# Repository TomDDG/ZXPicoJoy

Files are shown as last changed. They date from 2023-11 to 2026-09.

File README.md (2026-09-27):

# ZXPicoJoy
Programmable Joystick Interface for the ZX Spectrum using a Raspberry Pico.

Supports:
- Kempston
- Sinclair 1 & 2
- Cursor
- Any key combination

Uses an OLED and buttons to program and does not interfere with the Spectrum unless it is supposed to.

## The PCB
PCB designed to have all the components on the side away from the Spectrum to give more room. The edge connector then sits on the back side as well as the OLED so this is visible to the user. This is also why the buttons are reversed. 
### PCB v1.6c Front
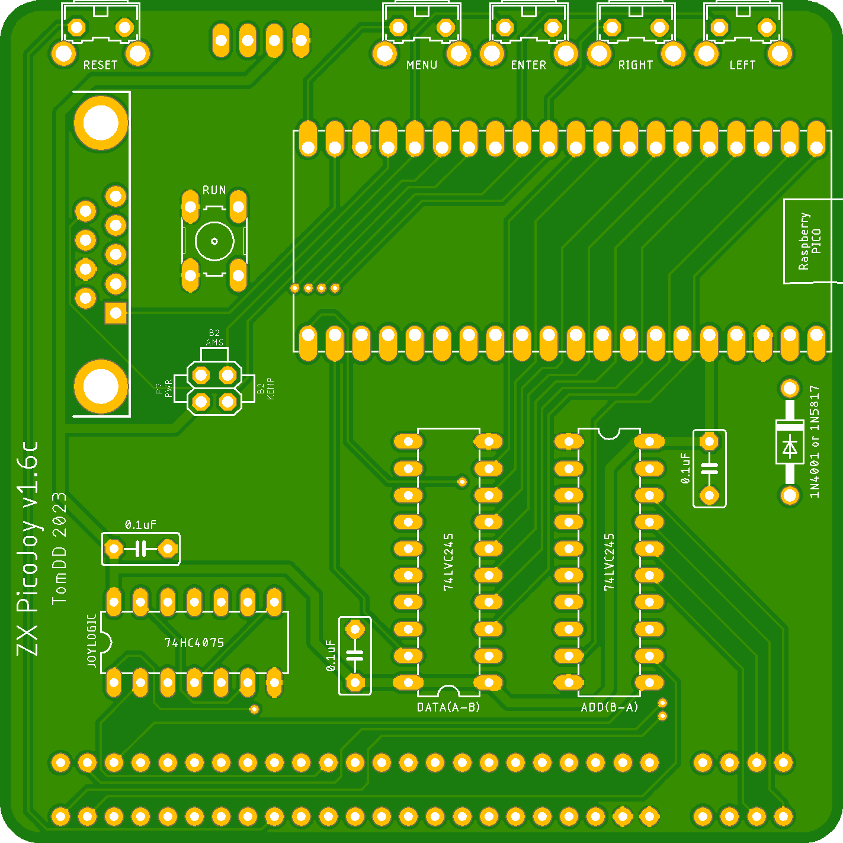
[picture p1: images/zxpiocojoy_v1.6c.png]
PCB Front

### PCB v1.6c Back
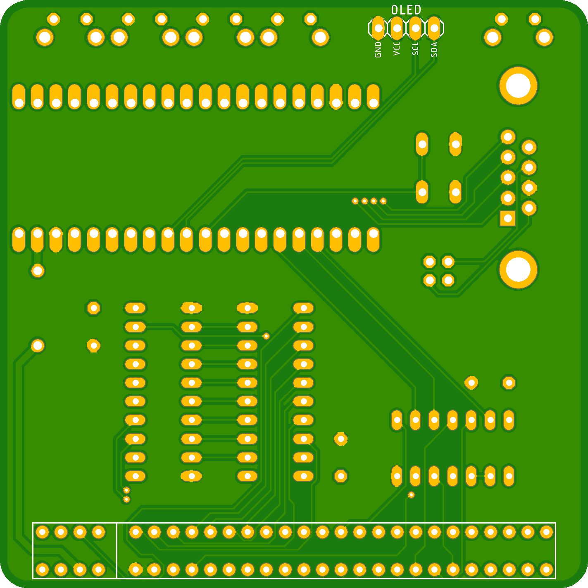
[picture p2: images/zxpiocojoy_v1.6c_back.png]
PCB Back


### Joystick Pin-Out

The joystick is wired for 3 button Kempston (Amiga) with the option to flip button 2 to pin 7 enabling the use of 2 button Amstrad joysticks. There is also an option to supply power to pin 7 for autofire circuits. It is wired to 3V3 instead of 5V so may not work on all joysticks, however, all the ones I have tried work fine as they are simple transistor circuits.

- Pin 1: Up
- Pin 2: Down
- Pin 3: Left
- Pin 4: Right
- Pin 5: Button 3
- Pin 6: Button 1
- Pin 7: Button 2 for Amstrad compatibility, not connected or 3V3
- Pin 8: GND
- Pin 9: Button 2 or not connected

### Bill of Materials (BoM)
- 1x [Raspberry Pico](https://shop.pimoroni.com/products/raspberry-pi-pico?variant=40059364311123). Recommend H variant as header pre-soldered.
- 2x [SN74LVC245AN Octal Bus Transceiver With 3-State Outputs](https://www.mouser.co.uk/ProductDetail/595-SN74LVC245AN). Note these need to be the LVC variant to work with the 3v3 of the Pico.
  - Optional 2x10pin sockets
- 1x [CDx4HC4075 Triple 3-Input OR Gates](https://www.mouser.co.uk/ProductDetail/595-CD74HC4075EE4). Note these need to be the HC variant in order to work with 3V3 supply voltage.
  - Optional 2x7pin socket
- 3x [100nF/0.1uF Capacitor](https://www.mouser.co.uk/ProductDetail/Vishay-BC-Components/K104K15X7RF5TH5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) 
- 1x [1N4001 Diode](https://www.mouser.co.uk/ProductDetail/Rectron/1N4001-B?qs=%252BtLcN0raKGUACwkD5chVvg%3D%3D) or [1N5158 Diode](https://www.mouser.co.uk/ProductDetail/STMicroelectronics/1N5817?qs=JV7lzlMm3yKNnxZdh%252BSMnw%3D%3D)
- 1x [56pin PCB Edge Connector](https://www.ebay.co.uk/sch/i.html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). Needs both ends cutting off, the pins removing top & bottom at position 5 and a piece of plastic or metal inserting for the slot (see [ZX Spectrum Edge Connector](https://i0.wp.com/projectspeccy.com/documents/ZXSpectrum_Edge_Connector_Diagram_48K.jpg)). This ensures everything aligns when connecting.
- 2x [20pin female header sockets](https://www.ebay.co.uk/sch/i.html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)
- 5x [6x6x9mm Right Angled PCB Momentary Push Button](https://www.ebay.co.uk/sch/i.html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)
- 1x [6x6x9mm PCB Momentary Push Button](https://www.ebay.co.uk/sch/i.html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)
- 1x [DE9 9pin Male PCB Connector](https://www.ebay.co.uk/sch/i.html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)
- 1x 4pin PCB header socket 2.54mm Pitch
- 1x SSD1306 OLED 0.96" (you can get larger ones just make sure they are SSD1306). Be very careful of the GND & VCC placement as they are sometimes reversed.
- 1x 2x2pin PCB pin header + jumpers

### Photos
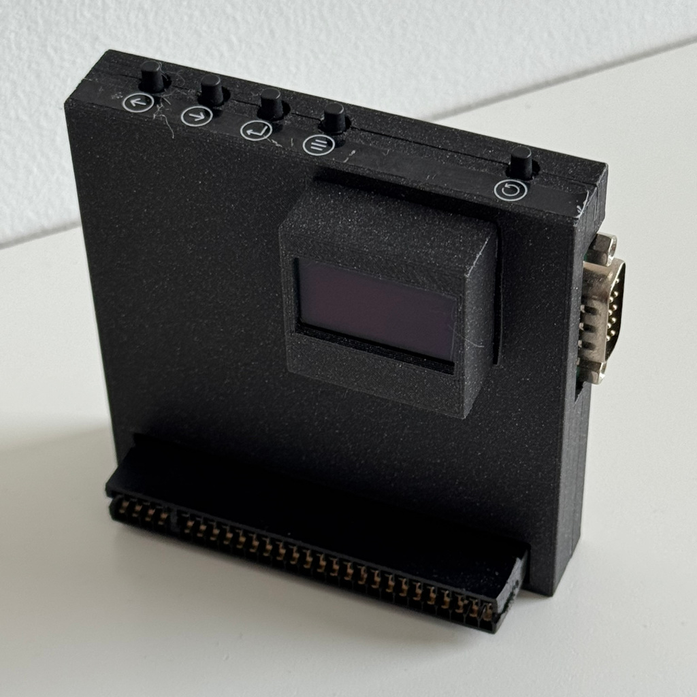
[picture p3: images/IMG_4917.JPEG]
Unit Front

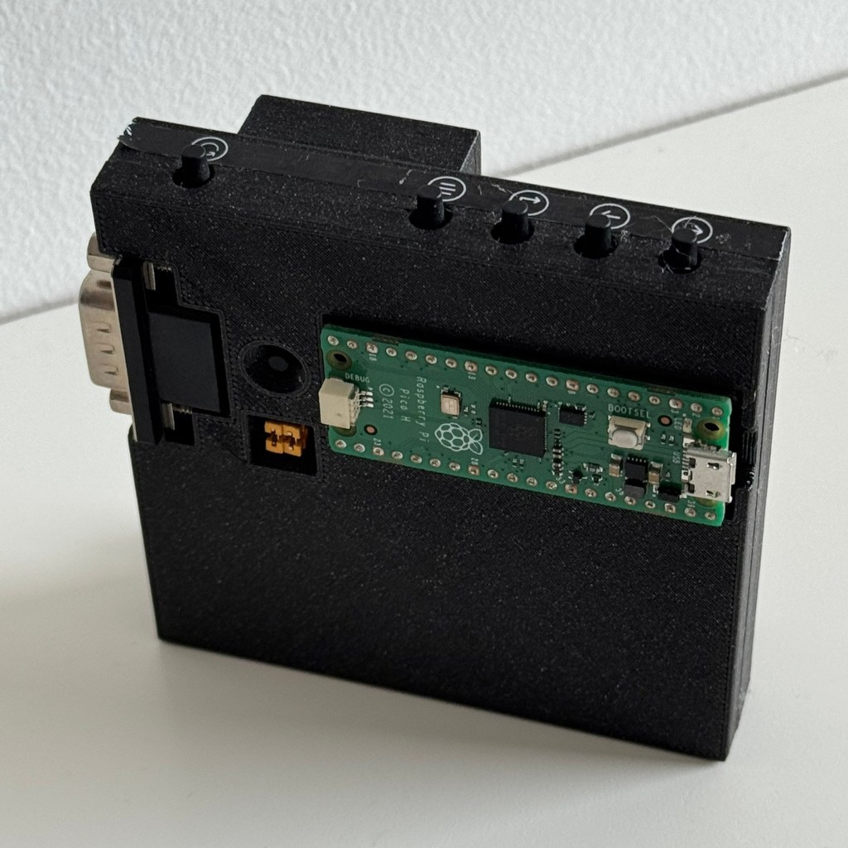
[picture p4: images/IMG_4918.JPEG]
Unit Back

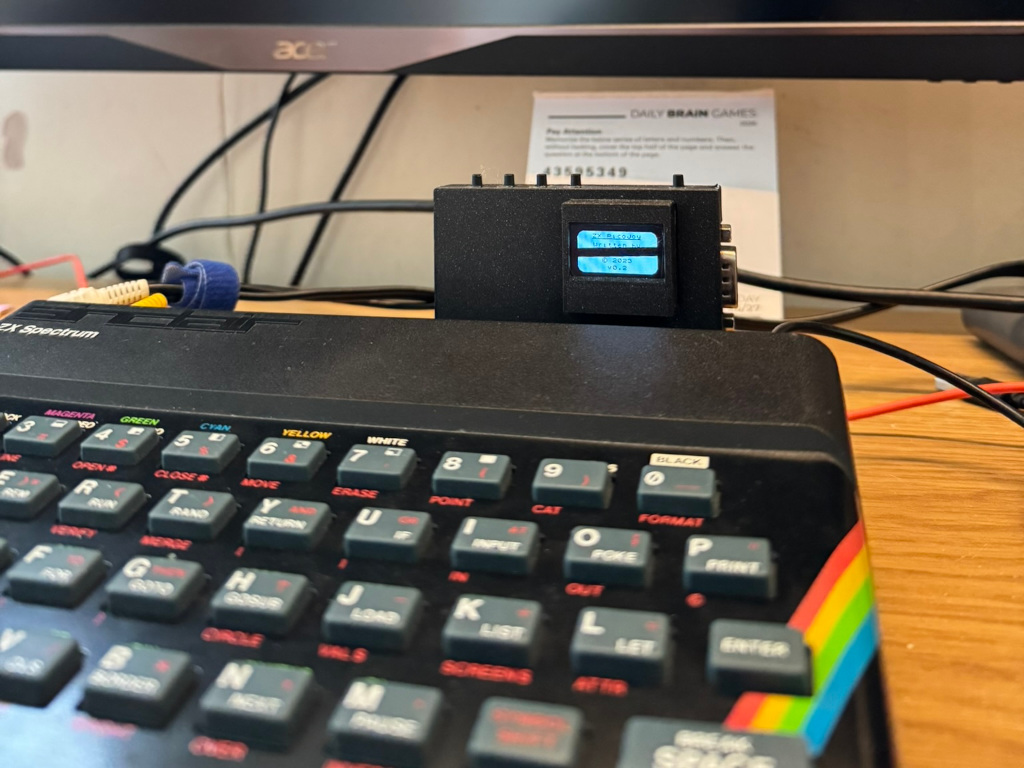
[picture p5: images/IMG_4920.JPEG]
Plugged In

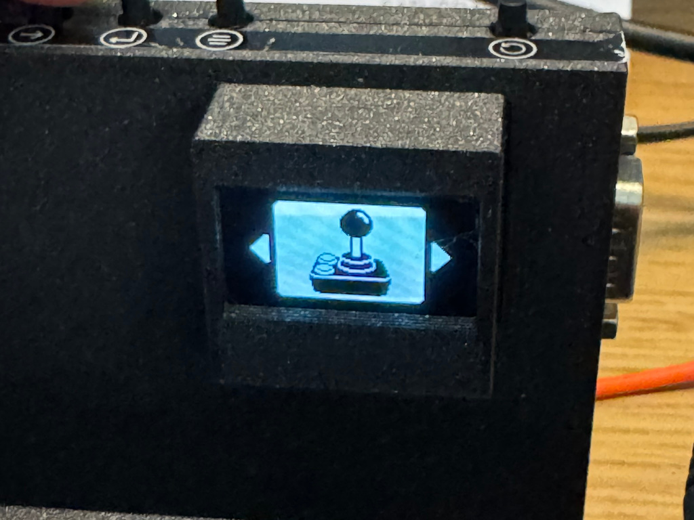
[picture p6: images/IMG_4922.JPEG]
Option 1

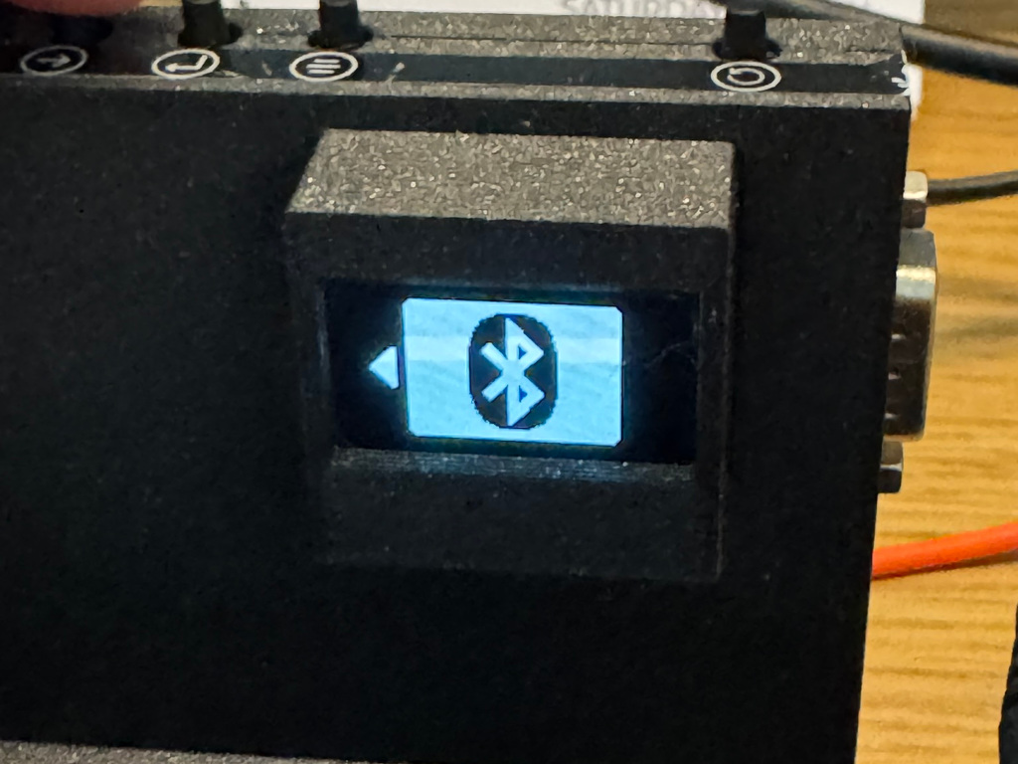
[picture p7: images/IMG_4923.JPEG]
Option 3

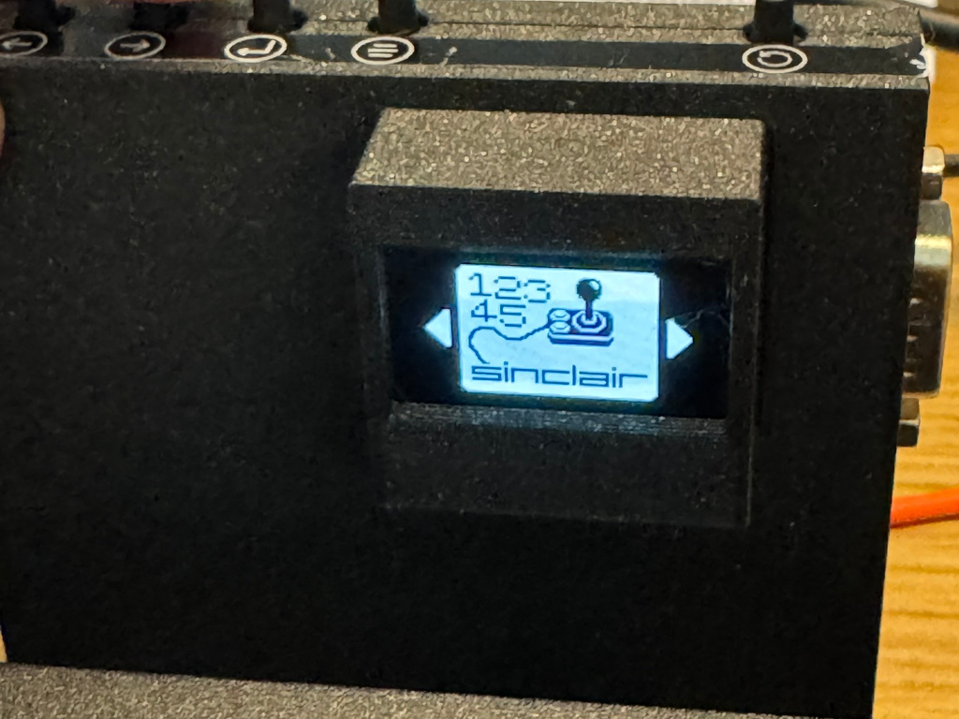
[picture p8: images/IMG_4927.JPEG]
Option 4

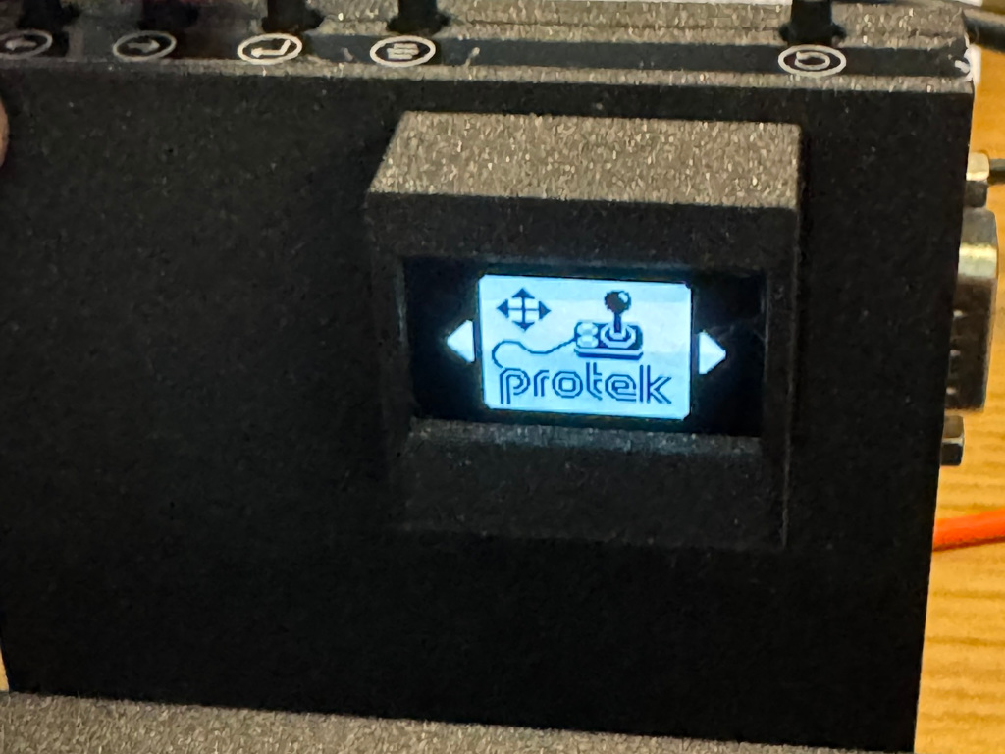
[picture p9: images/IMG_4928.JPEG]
Option 5

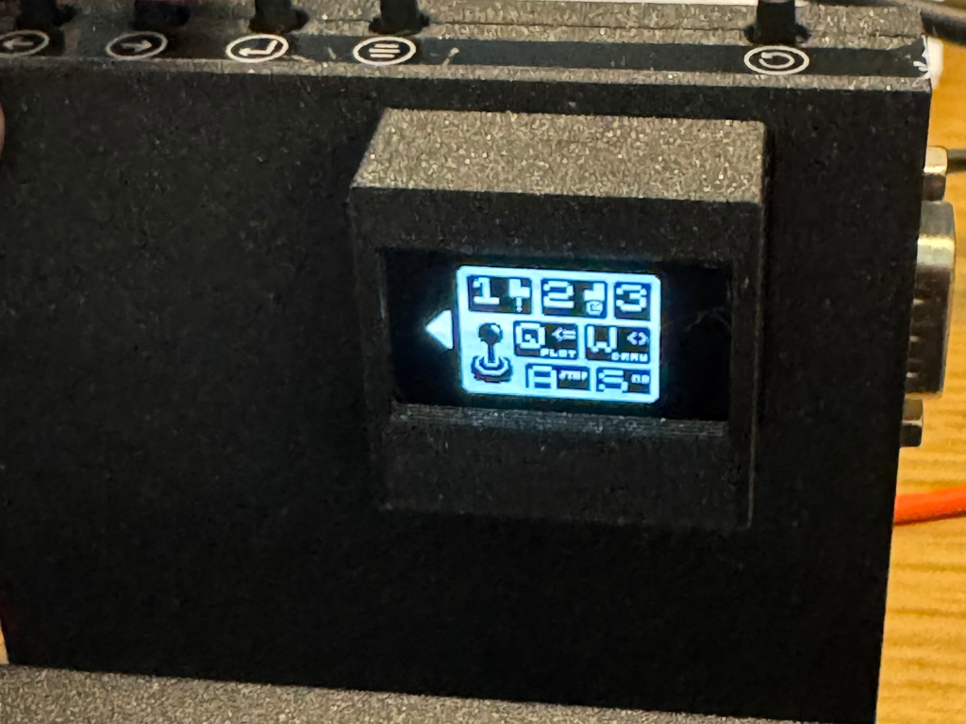
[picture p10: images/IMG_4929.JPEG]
Option 7


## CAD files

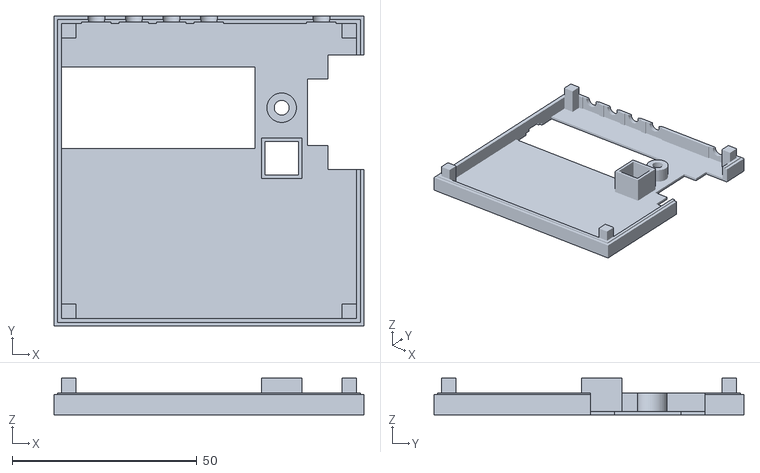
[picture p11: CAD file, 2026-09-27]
stl/zxpicojoy_top_v1.6bPCB_v0.1.stl
84.0 x 84.0 x 10.0

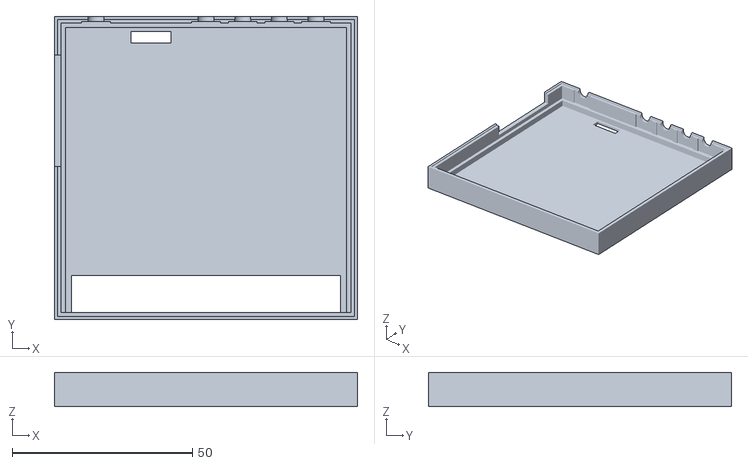
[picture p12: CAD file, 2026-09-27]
stl/zxpicojoy_bottom_v0.1.stl
84.0 x 84.0 x 9.50

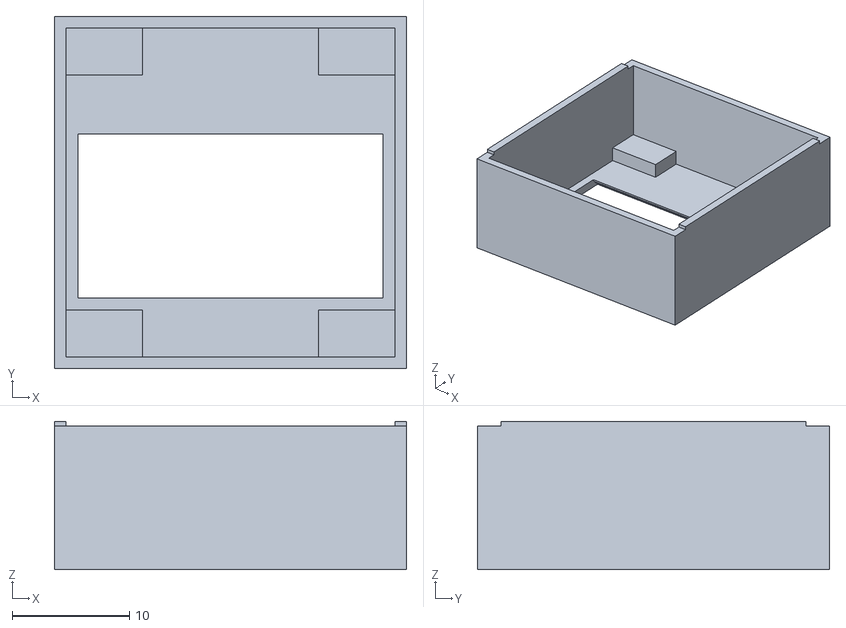
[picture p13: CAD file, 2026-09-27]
stl/zxpicojoy_oled_v0.2.stl
30.0 x 30.0 x 12.6

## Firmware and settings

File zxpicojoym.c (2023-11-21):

// Versions
// v0.1 initial release copied from v0.2 of ZX PicoJoy
// v0.2 added button 3 mapping
//
#define PROG_NAME   "ZX PicoJoyM"
#define VERSION_NUM "v0.2"
//
// ---------------------------------------------------------------------------
// includes
// ---------------------------------------------------------------------------
#include <stdio.h>
#include <string.h>
#include <stdlib.h>
#include "pico/stdlib.h"
//
#include "zxpicojoym.pio.h"
#include "zxpicojoym_k.pio.h"
#include "zxpicojoypress.pio.h"
//
#include "hardware/pio.h"
#include "hardware/dma.h"
#include "hardware/flash.h"
#include "hardware/i2c.h" // for OLED
//
#define SET_SPLASH 2000
#define KEY_REPEAT_LONG 500000
#define KEY_REPEAT_SHORT 200000
//
// ---------------------------------------------------------------------------
// GPIO Assignments
// ---------------------------------------------------------------------------
// 0 A8/D0
#define PIN_A8D0    0
// 1 A9/D1
// 2 A10/D2
// 3 A11/D3
// 4 A12/D4
// 5 A13/D5
// 6 A14/D6
// 7 A15/D7
//
// 8 RIGHT (ph) rldu123m
#define MAP_MBUDLR  0b1001111100000000
#define MAP_MBLR    0b1001001100000000
//
#define PIN_RIGHT   8
#define MAP_RIGHT   0b0000000100000000
// 9 LEFT (ph)
#define PIN_LEFT    9
#define MAP_LEFT    0b0000001000000000
// 10 DOWN (ph)
#define PIN_DOWN    10
#define MAP_DOWN    0b0000010000000000
// 11 UP (ph)
#define PIN_UP      11
#define MAP_UP      0b0000100000000000
// 12 BUTTON 1 (ph) also ENTER in MENU
#define PIN_B1      12
#define MAP_B1      0b0001000000000000
// 13 BUTTON 2 (ph)
#define PIN_B2      13
#define MAP_B2      0b0010000000000000
// 13 BUTTON 3 (ph)
#define PIN_B3      14
#define MAP_B3      0b0100000000000000
// 15 MENU (ph)
#define PIN_MENU    15
#define MAP_MENU    0b1000000000000000
// 16 ADDON
#define PIN_ADDON   16
// 17 DATAON
#define PIN_DATAON  17
// 18 A5RD
#define PIN_A5RD    18
// 19 KEMP
#define PIN_KEMP    19
// 20 KEYRD
#define PIN_KEYRD   20
// 21 NC
// 22 NC
// 23 NC
// 24 NC
// 25 NC
// 26 SDA (OLED)
#define PIN_SDA     26
// 27 SCL (OLED)
#define PIN_SCL     27
// 28 NC
//
// ---------------------------------------------------------------------------
// I/O Chips
// ---------------------------------------------------------------------------
// BUFFER 1 (3V3) DATA(A-B) -> DATON(P) Switches ON(0)/OFF(1)
// D0A8(P)   -> D0(E)
// D1A9(P)   -> D1(E)
// D2A10(P)   -> D2(E)
// D3A11(P)   -> D3(E)
// D4D12(P)   -> D4(E)
// D5A13(P)   -> D5(E)
// D6A14(P)   -> D6(E)
// D7A15(P)   -> D7(E)
// DATAON OE
//
// BUFFER 2 (3V3) ADD(B-A) -> ALWAY ON
// D0A8(P)  <- A8(E)
// D1A9(P)  <- A9(E)
// D2A10(P) <- A10(E)
// D3A11(P) <- A11(E)
// D4A12(P) <- A12(E)
// D5A13(P) <- A13(E)
// D6A14(P) <- A14(E)
// D7A15(P) <- A15(E)
// ADDON OE
//
// LOGIC OR (3V3)
// IORQ(E)+RD(E)+A0(E)   -> KEYRD(P)
// A5(E)+IORQ(E)+RD(E)   -> A5RD(O)
// A6(E)+A7(E)+A5RD(O)   -> KEMP(P)
//
// ---------------------------------------------------------------------------
// keyRow which address to alter
// keyCol which bit to alter
// ---------------------------------------------------------------------------
    const uint8_t keyRow[]= { 3,3,3,3,3, // 1,2,3,4,5
                              4,4,4,4,4, // 6,7,8,9,0
                              2,2,2,2,2, // Q,W,E,R,T
                              5,5,5,5,5, // Y,U,I,O,P
                              1,1,1,1,1, // A,S,D,F,G
                              6,6,6,6,6, // H,J,K,L,ENTER
                              0,0,0,0,0, // SHIFT,Z,X,C,V
                              7,7,7,7,7, // B,N,M,SS,SPACE
                              0 }; // kempston
    //  
    const uint8_t keyCol[]= {   0b10111110, // 1
                                0b10111101, // 2
                                0b10111011, // 3 
                                0b10110111, // 4
                                0b10101111, // 5
                                //
                                0b10101111, // 6
                                0b10110111, // 7
                                0b10111011, // 8
                                0b10111101, // 9
                                0b10111110, // 0
                                //
                                0b10111110, // Q
                                0b10111101, // W
                                0b10111011, // E
                                0b10110111, // R
                                0b10101111, // T
                                //
                                0b10101111, // Y
                                0b10110111, // U
                                0b10111011, // I
                                0b10111101, // O
                                0b10111110, // P
                                //
                                0b10111110, // A
                                0b10111101, // S
                                0b10111011, // D
                                0b10110111, // F
                                0b10101111, // G
                                //
                                0b10101111, // H
                                0b10110111, // J
                                0b10111011, // K
                                0b10111101, // L
                                0b10111110, // ENTER
                                //
                                0b10111110, // SHIFT
                                0b10111101, // Z
                                0b10111011, // X
                                0b10110111, // C
                                0b10101111, // V
                                //
                                0b10101111, // B
                                0b10110111, // N
                                0b10111011, // M
                                0b10111101, // SS
                                0b10111110, // SPACE
                                //
                                0b11111111 // kempston
                                };
//
// ---------------------------------------------------------------------------
// OLED structure
// ---------------------------------------------------------------------------
typedef struct {
    uint8_t w;      // width 128
    uint8_t h;      // height 64
    uint8_t p;      // pages 8
    uint8_t a;      // i2c address of display
    i2c_inst_t *i;  // i2c connection instance
    bool e;         // whether display uses external vcc
    uint8_t *c;	    // display buffer with command
    uint8_t *b;	    // display buffer 
    size_t s;		// total display buffer size
} oled_t;
#define MEMSIZE 1025 // 128*64=8192bits -> 1024bytes + 1 byte
#define MEMS_OLED 0 // start of main buffer used for OLED buffer
uint8_t mem_buffer[MEMSIZE];
//
// ---------------------------------------------------------------------------
// OLED command constants
// ---------------------------------------------------------------------------
#define SET_CONTRAST        0x81
#define SET_ENTIRE_ON       0xA4
#define SET_NORM_INV        0xA6
#define SET_DISP            0xAE
#define SET_MEM_ADDR        0x20
#define SET_COL_ADDR        0x21
#define SET_PAGE_ADDR       0x22
#define SET_DISP_START_LINE 0x40
#define SET_SEG_REMAP       0xA0
#define SET_MUX_RATIO       0xA8
#define SET_COM_OUT_DIR     0xC0
#define SET_DISP_OFFSET     0xD3
#define SET_COM_PIN_CFG     0xDA
#define SET_DISP_CLK_DIV    0xD5
#define SET_PRECHARGE       0xD9
#define SET_VCOM_DESEL      0xDB
#define SET_CHARGE_PUMP     0x8D
//
// ---------------------------------------------------------------------------
// functions
// ---------------------------------------------------------------------------
void runOLEDcmd(oled_t *pOLED,uint8_t v);
void dtoBuffer(uint8_t *to,const uint8_t *from);
void showOLED(oled_t *pOLED,uint8_t col,uint8_t page,size_t size);
void oledInit(oled_t *pOLED,uint8_t w,uint8_t h,uint8_t a,i2c_inst_t *i,bool e);
void pltIcons(uint8_t row,uint8_t col,const uint8_t *icon,uint8_t *to,bool invert);
void pltAllIcons(uint8_t *to,uint8_t iconStart,uint8_t iconPos);
void pltIcon(const uint8_t *icon,uint8_t *to);
uint8_t getKey(oled_t *pOLED, uint8_t *to,uint8_t iconShift);
void menu(oled_t *pOLED, uint8_t *to);
void writeConfig();
void clrFlash(oled_t *pOLED, uint8_t *to);
void resetAll();
//
// ---------------------------------------------------------------------------
// menu layout
// ---------------------------------------------------------------------------
#include "scr_img.h"
const uint8_t *scrimg[] = { scr_00, // 0
                            scr_01, // 1
                            scr_0101,scr_010001a,scr_010001b,scr_010002,scr_010003, //  2, 3, 4, 5, 6
                            scr_0102,scr_010001a,scr_010001b,scr_010002,scr_010003, //  7, 8, 9,10,11
                            scr_0103,scr_010001a,scr_010001b,scr_010002,scr_010003, // 12,13,14,15,16
                            scr_0104,scr_010001a,scr_010001b,scr_010002,scr_010003, // 17,18,19,20,21
                            scr_0105,scr_010001a,scr_010001b,scr_010501,scr_010502,scr_010503,scr_010504,scr_010505,scr_010002,scr_010003, // 22,23,24,25,26,27,28,29,30,31
                            scr_02, // 32
                            scr_0201,scr_0202, // 33,34
                            scr_010001c, // 35
                            scr_reset // 36
                             }; 
//
// ---------------------------------------------------------------------------
// action on enter press
// ---------------------------------------------------------------------------
// =0 do nothing
// <128 move to screen x
// =128 key selector 1
// =129 key selector 2 (includes additiohnal buttons)
// =130 activate (reset 3,7,11,15,19)
// =131 reset flash
//                           ss  jy  kp  a1  a2  b2  b3  s1  a1  a2  b2  b3  s2  a1  a2  b2  b3  cr  a1  a2  b2  b3  ky  a1  a2  up  dn  lf  rg  b1  b2  b3  bt  ps  xb  sw  rs
//                            0   1   2   3   4   5   6   7   8   9  10  11  12  13  14  15  16  17  18  19  20  21  22  23  24  25  26  27  28  29  30  31  32  33  34  35  36
const uint8_t scrEnter[] = {    0,  
                                2,  
                                3,130,  0,129,129,
                                8,130,  0,129,129,
                               13,130,  0,129,129,
                               18,130,  0,129,129,
                               23,130,  0,128,128,128,128,128,129,129,
                               33,
                                0,  0,
                                0,
                              131};
//
// ---------------------------------------------------------------------------
// icon swap, what to swap to. also used to determine which joystick selected
// ---------------------------------------------------------------------------
//                   ss jy kp a1 a2 b2 b3 s1 a1 a2 b2 b3 s2 a1 a2 b2 b3 cr a1 a2 b2 b3 ky a1 a2 up dn lf rg b1 b2 b3 bt ps xb sw rs
//                    0  1  2  3  4  5  6  7  8  9 10 11 12 13 14 15 16 17 18 19 20 21 22 23 24 25 26 27 28 29 30 31 32 33 34 35 36
uint8_t scrSwap[] = { 0, 0, 0, 0, 0, 0, 0, 0, 1, 0, 0, 0, 0, 0, 0, 0, 0, 0, 0, 0, 0, 0, 0, 0, 0, 0, 0, 0, 0, 0, 0, 0, 0, 0, 0, 0, 0};
//
#define swapto 35
//
#define swp_kp 3 // kempston
#define swp_s1 8 // sinclair 1
#define swp_s2 13 // sinclair 2
#define swp_cr 18 // cursor
#define swp_ky 23 // keyboard
//
#define b2_kp 5
#define b3_kp 6
#define b2_s1 10
#define b3_s1 11
#define b2_s2 15
#define b3_s2 16
#define b2_cr 20
#define b3_cr 21
//
#define up_ky 25
#define dn_ky 26
#define lf_ky 27
#define rg_ky 28
#define b1_ky 29
#define b2_ky 30
#define b3_ky 31
//
// ---------------------------------------------------------------------------
// next, previous what screen to move to (0 means can't move)
// ---------------------------------------------------------------------------
//                         ss jy kp a1 a2 b2 b3 s1 a1 a2 b2 b3 s2 a1 a2 b2 b3 cr a1 a2 b2 b3 ky a1 a2 up dn lf rg b1 b2 b3 bt ps xb sw rs
//                          0  1  2  3  4  5  6  7  8  9 10 11 12 13 14 15 16 17 18 19 20 21 22 23 24 25 26 27 28 29 30 31 32 33 34 35 36
const uint8_t scrNext[] = { 0,32, 7, 5, 5, 6, 0,12,10,10,11, 0,17,15,15,16, 0,22,20,20,21, 0, 0,25,25,26,27,28,29,30,31, 0, 0,34, 0, 0, 1};
//                         ss jy kp a1 a2 b2 b3 s1 a1 a2 b2 b3 s2 a1 a2 b2 b3 cr a1 a2 b2 b3 ky a1 a2 up dn lf rg b1 b2 b3 bt ps xb sw rs
//                          0  1  2  3  4  5  6  7  8  9 10 11 12 13 14 15 16 17 18 19 20 21 22 23 24 25 26 27 28 29 30 31 32 33 34 35 36
const uint8_t scrPrev[] = { 0,36, 0, 0, 0, 3, 5, 2, 0, 0, 8,10, 7, 0, 0,13,15,12, 0, 0,18,20,17, 0, 0,23,25,26,27,28,29,30, 1, 0,33, 0, 0};
//
// ---------------------------------------------------------------------------
// config
// 0-9 header (ZXPicoJoyM)
// 10 current joystick selected (using scrSwap)
// 11 kempston b2
// 12 sinclair1 b2
// 13 sinclair2 b2
// 14 cursor b2
// 15-21 keys (inc. b3)
// 22 kempston b3
// 23 sinclair1 b3
// 24 sinclair2 b3
// 25 cusor b3
// ---------------------------------------------------------------------------
//                         h   h   h   h   h   h   h   h   h   h  wj b2 b2 b2 b2 ky ky ky ky ky ky ky b3 b3 b3 b3
//                         0   1   2   3   4   5   6   7   8   9  10 11 12 13 14 15 16 17 18 19 20 21 22 23 24 25
const uint8_t config_d[]={'Z','X','P','i','c','o','J','o','y','M', 8, 1, 2, 2, 2,14,24,22,23,41,29,28, 0, 2, 2, 2};
#define cfg_cjy 10
#define cfg_kp2 11
#define cfg_s12 12
#define cfg_s22 13
#define cfg_cr2 14
#define cfg_key 15
#define cfg_ky2 20
#define cfg_ky3 21
#define cfg_kp3 22
#define cfg_s13 23
#define cfg_s23 24
#define cfg_cr3 25
#define cfg_end 26
uint8_t config[256];
//
// ---------------------------------------------------------------------------
// flash config allocated 256bytes
// if not present use default and create, otherwise read in
// ---------------------------------------------------------------------------
#define FLASH_TARGET_OFFSET (256 * 1024)
const uint8_t *flash_target_contents = (const uint8_t *) (XIP_BASE + FLASH_TARGET_OFFSET);
//
// ---------------------------------------------------------------------------
// default keys and mappings
// ---------------------------------------------------------------------------
uint8_t keySel[7]; 
// maps to a key, 44 (-4=40) is do nothing, 0=b3, 1=b2, 2=b1, 3=up
// the keys in selector rows 
uint8_t kmpSel[7] = {44,44,44,44,44, 1, 0}; 
uint8_t s1Sel[7]  = {12,11, 9,10,13, 2, 2};
uint8_t s2Sel[7]  = { 7, 6, 4, 5, 8, 2, 2};
uint8_t curSel[7] = {10, 9, 8,11,13, 2, 2};
//
// ---------------------------------------------------------------------------
// key icons
//   0-b3  1-b2  2-b1  3-up
//   4-1   5-2   6-3   7-4
//   8-5   9-6  10-7  11-8  
//  12-9  13-0  14-q  15-w
//  16-e  17-r  18-t  19-y
//  20-u  21-i  22-o  23-p
//  24-a  25-s  26-d  27-f
//  28-g  29-h  30-j  31-k
//  32-l  33-en 34-cs 35-z
//  36-x  37-c  38-v  39-b
//  40-n  41-m  42-ss 43-sp
// ---------------------------------------------------------------------------
#include "icons.h"
const uint8_t *icons[]={ icon_b3,icon_b2,icon_b1,icon_up,
                         icon_1,icon_2,icon_3,icon_4,
                         icon_5,icon_6,icon_7,icon_8,
                         icon_9,icon_0,icon_q,icon_w,
                         icon_e,icon_r,icon_t,icon_y,
                         icon_u,icon_i,icon_o,icon_p,
                         icon_a,icon_s,icon_d,icon_f,
                         icon_g,icon_h,icon_j,icon_k,
                         icon_l,icon_en,icon_cs,icon_z,
                         icon_x,icon_c,icon_v,icon_b,
                         icon_n,icon_m,icon_ss,icon_sp                     
                         };
//
// ---------------------------------------------------------------------------
// main program
// ---------------------------------------------------------------------------
void main() {   
    //
    // ---------------------------------------------------------------------------------------
    // On PICO boot all gpio pins are set to input, 4ma drive strength, pull down and schmitt 
    // trigger enabled. On Spectrum boot M1 (read instruction) goes low after ~100ms so need 
    // stablility before this turning off both buffers first takes 19.6ms which is quick 
    // enough to ensure no interference with either address or data lines. Another option 
    // would be to control the RESET line using the PICO but not enough GPIO pins
    // ---------------------------------------------------------------------------------------
    //
    gpio_init(PIN_ADDON); // address on(0)/off(1)
    gpio_set_dir(PIN_ADDON,true); // set to out
    gpio_put(PIN_ADDON,1); // off till needed    
    gpio_init(PIN_DATAON); // data on(0)/off(1)
    gpio_set_dir(PIN_DATAON,true); //  set to out
    gpio_put(PIN_DATAON,1); // off till needed
    //
    gpio_init(PIN_KEYRD); // keyread
    gpio_set_dir(PIN_KEYRD,true); //  set to out
    gpio_put(PIN_KEYRD,1); // off till needed
    gpio_init(PIN_KEMP); // kempston
    gpio_set_dir(PIN_KEMP,true); //  set to out
    gpio_put(PIN_KEMP,1); // off till needed
    gpio_init(PIN_A5RD); // A5 (mouse) 
    gpio_set_dir(PIN_A5RD,true); //  set to out
    gpio_put(PIN_A5RD,1); // off till needed
    //
    // ---------------------------------------------------------------------------------------
    // for debugging
    // stdio_init_all();
    // while(!stdio_usb_connected());    
    // ---------------------------------------------------------------------------------------
    //
    // ---------------------------------------------------------------------------------------
    // button GPIOs & pull-ups, all are pull up so active wen connected to ground. 
    // Same as the hardware joystick
    // ---------------------------------------------------------------------------------------
    gpio_init(PIN_LEFT); 
    gpio_set_dir(PIN_LEFT,false); // input   
    gpio_pull_up(PIN_LEFT); // pull high so pressing goes low   
    gpio_init(PIN_RIGHT); 
    gpio_set_dir(PIN_RIGHT,false); // input        
    gpio_pull_up(PIN_RIGHT); 
    gpio_init(PIN_UP); 
    gpio_set_dir(PIN_UP,false); // input  
    gpio_pull_up(PIN_UP);
    gpio_init(PIN_DOWN); 
    gpio_set_dir(PIN_DOWN,false); // input  
    gpio_pull_up(PIN_DOWN);
    gpio_init(PIN_B1); 
    gpio_set_dir(PIN_B1,false); // input  
    gpio_pull_up(PIN_B1);
    gpio_init(PIN_B2); 
    gpio_set_dir(PIN_B2,false); // input       
    gpio_pull_up(PIN_B2); 
    gpio_init(PIN_B3); 
    gpio_set_dir(PIN_B3,false); // input       
    gpio_pull_up(PIN_B3); 
    gpio_init(PIN_MENU); 
    gpio_set_dir(PIN_MENU,false); // input    
    gpio_pull_up(PIN_MENU); 
    //
    // master dataset used to pass data from DMA to PIO, algined to 256 boundary so can use absolute address i.e. address pins = memory address
    volatile uint8_t dataout[256] __attribute__((aligned (256))); // for all address combinations (8bits)  
    volatile uint8_t joypress=0b11111111;    
    volatile uint8_t kemppress=0b00000000;
    //
    // ---------------------------------------------------------------------------------------
    // Set-up PIO, 4 state machines (SM) per PIO, 2 PIOs each with 4 SMs -> 1 PIO used & 3 SMs
    // PIO 0
    //   SM1 13 instructiuons: read address, write data, uses DMA
    //   SM2 2 instructions: read joystick, write to single byte, uses DMA
    //   SM3 7 instructions: write data, uses DMA
    // 22 instructions, max 32
    //
    // Also set-up associatedDMAs, 12 channels in total, 6 used
    // for SM2 & SM3 the DMA channels are identical and used to call each other
    // ---------------------------------------------------------------------------------------
    PIO pio=pio0; // use pio 0
    //      
    // ---------------------------------------------------------------------------------------
    // keyboard (PIO 0, SM 1)
    // ---------------------------------------------------------------------------------------
    uint joy_data_sm=pio_claim_unused_sm(pio,true); // grab an free state machine from PIO 0
    uint joy_data_offset=pio_add_program(pio,&zxpicojoym_program); // get instruction memory offset for the loaded program
    pio_sm_config joy_data_config=zxpicojoym_program_get_default_config(joy_data_offset); // get the default state machine config    
    sm_config_set_in_pins(&joy_data_config,PIN_A8D0);
    sm_config_set_in_shift(&joy_data_config,false,true,8); // shift left input pins into ISR, autopush
    // set-up OUT data pins
    for(uint i=PIN_A8D0;i<PIN_A8D0+8;i++) pio_gpio_init(pio,i); // initialise all 8 output pins, this is needed for ouput (not for input)
    sm_config_set_out_pins(&joy_data_config,PIN_A8D0,8); // set OUT pin base & number (bits)
    sm_config_set_out_shift(&joy_data_config,true,false,8); // right shift 8 bits of OSR to pins (D0-D7) with autopull off
    pio_sm_set_consecutive_pindirs(pio,joy_data_sm,PIN_A8D0,8,true); // set all output pins to output
    // set-up SET pins
    pio_gpio_init(pio,PIN_ADDON); // 
    pio_gpio_init(pio,PIN_DATAON);      
    sm_config_set_set_pins(&joy_data_config,PIN_ADDON,2);
    pio_sm_set_consecutive_pindirs(pio,joy_data_sm,PIN_ADDON,2,true);
    // initialise state machine but do not start yet
    pio_sm_init(pio,joy_data_sm,joy_data_offset,&joy_data_config); // reset state machine and configure it
    // 
    // ---------------------------------------------------------------------------------------
    // 2 DMAs for keyboard, 1 reads address from PIO -> 1 writes data to PIO
    // ---------------------------------------------------------------------------------------
    int addr_chan=dma_claim_unused_channel(true);
    int data_chan=dma_claim_unused_channel(true);
    // DMA move the requested memory data to PIO for output *DATA*
    dma_channel_config data_dma=dma_channel_get_default_config(data_chan); // default configuration structure
    channel_config_set_high_priority(&data_dma,true); // all high priority channels are considered first
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

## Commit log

2026-11-01 Add files via upload
    v0.3 fixed flash so config now saves correctly
    added paging to reduce flash erase. 16 pages cycled through
    added 10second timeout to the menu if no button pressed
2026-11-05 Add files via upload
    v0.4
    sorted out flash config (hopefully)
    added info screen to show current active joystick and button mappings
    add ability to reset the flash, hold down menu button on reset/power on for 1 second (duration of splash screen)
    add sub-menu (key select) timeout, goes back to main menu after 10 seconds
2026-11-05 Add files via upload
    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
